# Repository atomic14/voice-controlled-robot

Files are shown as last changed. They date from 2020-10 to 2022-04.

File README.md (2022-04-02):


# Voice-Controlled Robot With the ESP32

Build your own voice-controlled robot - all you will need is an ESP32 and Microphone board (and some motors etc...).

You can watch a video of the robot in action [here (YouTube)](https://www.youtube.com/watch?v=cp2qRrhaZRA):

Demo Video (https://www.youtube.com/watch?v=cp2qRrhaZRA)

I'm using a microphone breakout board that I've built myself based around the ICS-43434 - but any microphone board will work. The code has been written so that you can either use an I2S microphone or an analogue microphone using the built-in ADC.

I would recommend using an I2S microphone if you have one as they have a lot better noise characteristics.

My board is available on [eBay](https://www.ebay.co.uk/itm/154115095985) and [Tindie](https://www.tindie.com/products/atomic14/ics-43434-i2s-mems-microphone-breakout-board/)

Other I2S microphones are equally suitable. Boards based around the INMP441 work very well.

The voice recognition is carried out using a model trained with TensorFlow and runs on the ESP32 using TensorFlow Lite. A pre-trained model is included in the Firmware folder so you can get up and running straight away.

There are two folders in this repo `model` and `firmware` check the `README.md` file in each one for complete details.

## Model

Jupyter notebooks for creating a TensorFlow Lite model for "wake word" recognition.

A pre-trained model has already been generated and added to the firmware folder.

If you want to train your own, I added a couple of extra folders to the training data they are available here:

## Firmware

ESP32 firmware built using Platform.io. This runs the neural network trying to detect the words `Left`, `Right`, `Forward` and `Backward`.

The code assumes there are two continuous servos attached to the board such as the FS90R servo - these are readily available from various suppliers and you can normally buy them with wheels as well.

# 3dPrinting

This contains the 3d models that I used to build my 2 wheeled robot. It's designed around the FS90R continuous servos and a cylindrical power bank.

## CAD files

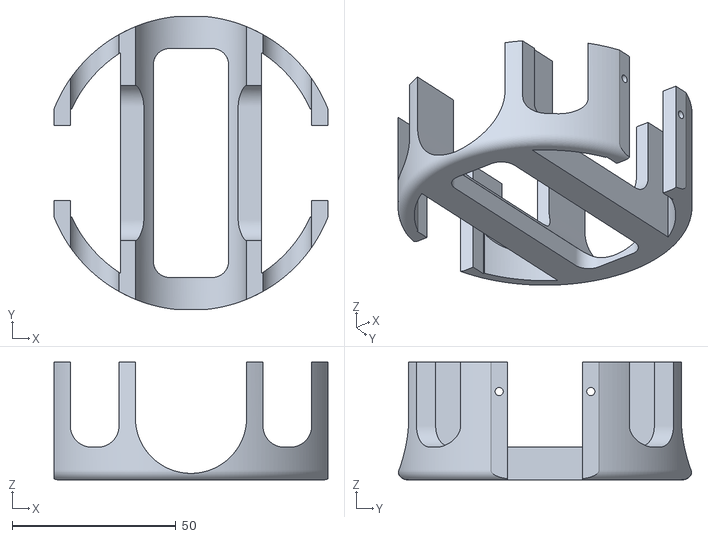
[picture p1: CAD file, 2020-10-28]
3dPrinting/2-wheeled-robot.stl
83.7 x 89.7 x 36.0

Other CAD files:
3dPrinting/2-wheeled-robot.f3z

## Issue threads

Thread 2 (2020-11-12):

Problems with CommandProcessor::processCommand and I2C

sthufnagl, 2020-11-12:
Hi,

I have a RoverC with I2C controlled Motors.
Because of this I try to change the "CommandProcessor::processCommand" and insert  some I2C Commands like below.
After the change (i.e. forward) it run once and then the Command recognition is broken. It seems related to the Wire.xxx Call.
Thanks in advance.

```
case 0: // forward
        ledcWrite(0, calcDuty(leftForward));
        ledcWrite(1, calcDuty(rightForward));
        vTaskDelay(1000 / portTICK_PERIOD_MS);
        break;
```

to
```
case 0: // forward
        Wire.beginTransmission(0X38);
        Wire...
        vTaskDelay(1000 / portTICK_PERIOD_MS);
        break;
```

sthufnagl, 2020-11-26:
Hi,

I found the solution for the M5StickC. The problem was the wrong init of I2C. How this influence the  "Command recognition" is still unknown for me.

Wrong: Wire.begin(0,26,1000);
OK:       Wire.begin(0,26,400000);

Thx

Closed 2020-11-26.

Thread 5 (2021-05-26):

Dear atomic14: there are somes question need your help, please give me some advice, thanks

maoyanru, 2021-05-26:
I have downloaded your project and it can be sucessfully compiled by platfromIo.I have been studying  for a few days,and i think i still need your guidance.
1、Can this project be completed only with esp32 and INMP441?
2、How to connect esp32 and INMP441 (the pin of INMP441 is connected to esp32)。
3、Can i use oscilloscope to view the waveform of INMP441 after powering on INMP441 alone(to make sure the INMP441 i bought is usable)
4、How to use jupyter notebook and Google Speech Commands Dataset (v0.02) to train other command model?Looking forward to you giving me the jupyter notebook project in this video for study。

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
Follow this picture to connect INMP441 and esp32 pin

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
this my hardware（esp32 and INMP441）,if i say "back"or "left" and then INMP441 detect key words,finally serial port print(testing successfully)~
                                                                                                               Think you for taking the time to reply my question
                                                                                                                your’s sincerely fans  Yao

fabiodavide97, 2021-05-27:
Dear Atomic14, i would use this project for my accademic project so i want know how change the code using 2 motor DC
Thanks for the answer

cgreening, 2021-06-07:
The best place to start would be the code in `CommandProcessor.cpp` the `processCommand` function is responsible for deciding what to do for each detected command.

At the moment it is simply changing the PWM signal to each motor. If you have a motor control board then this would be the place to make the changes.

cgreening, 2021-06-08:
@maoyanru did you solve the issues you were having?

Closed 2021-10-05.

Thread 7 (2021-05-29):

Dear Atomic14, I have some issue.

fabiodavide97, 2021-05-29:
When I run the code, appear this problem in Serial Monitor and the mic doesn't listen:

E (22702) task_wdt: Task watchdog got triggered. The following tasks did not reset the watchdog in time:
E (22702) task_wdt:  - IDLE0 (CPU 0)
E (22702) task_wdt: Tasks currently running:
E (22702) task_wdt: CPU 0: Command Detect
E (22702) task_wdt: CPU 1: loopTask

Can you help me, please ?

cgreening, 2021-06-07:
Hey Fabio,

I'll take a look. Have you made any modifications to the code?

Thanks
Chris

fabiodavide97, 2021-06-07:
I only changed the microphone connection pin:
sck ---> GPIO25
WS ----> GPIO33
SD ----> GPIO32
VDD --->3.3V
GND ---> GND

cgreening, 2021-06-07:
Hmm, that shouldn't make any difference. Let me run it up locally and see if something has changed with the underlying Arduino frameworks.

fabiodavide97, 2021-06-07:
could it be a microphone problem? I use an INMP441.

cgreening, 2021-06-07:
It should matter - though I guess if there's weird data coming from the microphone it could trigger some odd behaviour.

In the code, we see the watch dog timeout to 10 seconds so it really shouldn't be triggering at all.

```
  // make sure we don't get killed for our long running tasks
  esp_task_wdt_init(10, false);
```

This is what you should see on the output (I'm running this with no microphone connected at all).

```
Average detection time 103ms
Average detection time 103ms
Average detection time 103ms
Average detection time 103ms
Average detection time 103ms
Average detection time 103ms
Average detection time 103ms
Average detection time 103ms
```

cgreening, 2021-06-07:
I've added a vTaskDelay to the loop function - I'm not sure if will help as I can't create the issue - I'll do some more investigation this evening.

fabiodavide97, 2021-06-07:
Starting up
Loading model
12 bytes lost due to alignment. To avoid this loss, please make sure the tensor_arena is 16 bytes aligned.
Used bytes 22644

Output Size 1

Created Neral Net
m_pooled_energy_size=43
Created audio processor
Starting i2s
E (22715) task_wdt: Task watchdog got triggered. The following tasks did not reset the watchdog in time:
E (22715) task_wdt:  - IDLE0 (CPU 0)
E (22715) task_wdt: Tasks currently running:
E (22715) task_wdt: CPU 0: Command Detect
E (22715) task_wdt: CPU 1: IDLE1
Average detection time 155ms
E (32715) task_wdt: Task watchdog got triggered. The following tasks did not reset the watchdog in time:
E (32715) task_wdt:  - IDLE0 (CPU 0)
E (32715) task_wdt: Tasks currently running:
E (32715) task_wdt: CPU 0: Command Detect
E (32715) task_wdt: CPU 1: IDLE1
E (42715) task_wdt: Task watchdog got triggered. The following tasks did not reset the watchdog in time:
E (42715) task_wdt:  - IDLE0 (CPU 0)
E (42715) task_wdt: Tasks currently running:
E (42715) task_wdt: CPU 0: Command Detect
E (42715) task_wdt: CPU 1: IDLE1
Average detection time 155ms
E (52715) task_wdt: Task watchdog got triggered. The following tasks did not reset the watchdog in time:
E (52715) task_wdt:  - IDLE0 (CPU 0)
E (52715) task_wdt: Tasks currently running:
E (52715) task_wdt: CPU 0: Command Detect
E (52715) task_wdt: CPU 1: IDLE1

This is the Serial Monitor.

cgreening, 2021-06-07:
I think since the device is not restarting you can probably ignore the message. Though I'm not sure why you are seeing it with the watchdog pretty much disabled.

Onto your microphone issue - can you check that in the `config.h` file the line

```
#define USE_I2S_MIC_INPUT
```

Is not commented out. I noticed in the previous code that it was commented out which would switch the device into using the ADC instead of the I2S microphone.

cgreening, 2021-06-07:
Also, your detection time seems to be very slow. What device are you using?

fabiodavide97, 2021-06-07:
I'm using esp32

cgreening, 2021-06-07:
Which dev board are you using?

fabiodavide97, 2021-06-07:
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

cgreening, 2021-06-07:
Looks pretty standard. So there are a couple of places that you can debug your microphone.

In `CommandDetector.cpp` you can try logging out the value of `best_score` and `best_index` just after line 96.

In `AudioProcessor.cpp` you could log out the max value you are getting from the microphone - you can log out the value of max on line 114 and see if it changes when you speak into the microphone.

To really test it, you could try one of my other projects - the simplest one is probably `https://github.com/atomic14/ICS-43434-breakout-board` it hs a server that the samples are sent to so you can load into something like Audacity - or even just look at the data using hexdump to see if it has non zero values.

You can also just Serial print the values coming from the microphone.

cgreening, 2021-06-07:
I've tested the code locally here and all seems well, so I think your first step would be to confirm the microphone is working as expected.

cgreening, 2021-06-07:
I've created a really simple test sketch that you can use to test your microphone - let me know how you get on: https://github.com/atomic14/esp32-i2s-mic-test

fabiodavide97, 2021-06-07:
dear Atomic 14 the problem is the microphone because the code generates this waveform.
it does not detect sound waves. I don't know how to fix it and hope you can help me.
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

cgreening, 2021-06-07:
Double-check the wiring of your microphone - is it definitely wired up correctly?

Make sure the L/R pin is connected to GND.

If you draw out your connections I can double-check them for you.

cgreening, 2021-06-07:
Actually, I get exactly what you are seeing when the SD line is disconnected.

fabiodavide97, 2021-06-07:
Yes, the pin is correctly wireds up

fabiodavide97, 2021-06-07:
Dear Atomic 14 finally the code works. The problem was the microphone. Some pins were not soldered well and therefore made no contact.
Thank you so much for helping me.

fabiodavide97, 2021-06-07:
Dear Atomic 14, I would like to ask you something else. I have 2 DC motors connected to the L298N module. How can I modify the code to make them work?

cgreening, 2021-06-08:
Take a look here: https://github.com/atomic14/voice-controlled-robot/issues/5#issuecomment-855772115

Closed 2021-06-08.

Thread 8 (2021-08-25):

FreeRTOS dependency is missing

omakood, 2021-08-25:
Sorry, I'm beginner in PlatformIO and I can't compile the project:

Processing esp32doit-devkit-v1 (platform: espressif32; board: esp32doit-devkit-v1; framework: arduino)
------
Verbose mode can be enabled via `-v, --verbose` option
CONFIGURATION: https://docs.platformio.org/page/boards/espressif32/esp32doit-devkit-v1.html
PLATFORM: Espressif 32 (3.3.1) > DOIT ESP32 DEVKIT V1
HARDWARE: ESP32 240MHz, 320KB RAM, 4MB Flash
DEBUG: Current (esp-prog) External (esp-prog, iot-bus-jtag, jlink, minimodule, olimex-arm-usb-ocd, olimex-arm-usb-ocd-h, olimex-arm-usb-tiny-h, olimex-jtag-tiny, tumpa)
PACKAGES:
 - framework-arduinoespressif32 3.10006.210326 (1.0.6)
 - tool-esptoolpy 1.30100.210531 (3.1.0)
 - toolchain-xtensa32 2.50200.97 (5.2.0)
LDF: Library Dependency Finder -> http://bit.ly/configure-pio-ldf
LDF Modes: Finder ~ chain, Compatibility ~ soft
Found 32 compatible libraries
Scanning dependencies...
Dependency Graph
|-- <audio_processor>
|   |-- <audio_input>
|-- <audio_input>
|-- <neural_network>
|   |-- <tfmicro>
|-- <WiFi> 1.0
Building in release mode
Compiling .pio/build/esp32doit-devkit-v1/src/CommandDetector.cpp.o
Compiling .pio/build/esp32doit-devkit-v1/src/main.cpp.o
In file included from src/CommandDetector.cpp:2:0:
lib/audio_input/I2SSampler.h:3:31: fatal error: FreeRTOS/FreeRTOS.h: No such file or directory
compilation terminated.
Compiling .pio/build/esp32doit-devkit-v1/libbcc/audio_input/ADCSampler.cpp.o
In file included from lib/audio_input/ADCSampler.h:4:0,
Compiling .pio/build/esp32doit-devkit-v1/libbcc/audio_input/I2SMicSampler.cpp.o
                 from lib/audio_input/ADCSampler.cpp:1:
lib/audio_input/I2SSampler.h:3:31: fatal error: FreeRTOS/FreeRTOS.h: No such file or directory
compilation terminated.
*** [.pio/build/esp32doit-devkit-v1/src/CommandDetector.cpp.o] Error 1
*** [.pio/build/esp32doit-devkit-v1/libbcc/audio_input/ADCSampler.cpp.o] Error 1
In file included from lib/audio_input/I2SMicSampler.h:4:0,
                 from lib/audio_input/I2SMicSampler.cpp:1:
lib/audio_input/I2SSampler.h:3:31: fatal error: FreeRTOS/FreeRTOS.h: No such file or directory
compilation terminated.
*** [.pio/build/esp32doit-devkit-v1/libbcc/audio_input/I2SMicSampler.cpp.o] Error 1
In file included from lib/audio_input/I2SMicSampler.h:4:0,
                 from src/main.cpp:5:
lib/audio_input/I2SSampler.h:3:31: fatal error: FreeRTOS/FreeRTOS.h: No such file or directory
compilation terminated.
*** [.pio/build/esp32doit-devkit-v1/src/main.cpp.o] Error 1

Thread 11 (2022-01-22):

print(len(train), len(test), len(validate)) always returns 0 0 0

chrisakira, 2022-01-22:
I'm using tensorflow 2.7.0 installed on a VM with ubuntu 20.04.03

The output on the first process word part is

Processing words: 100%
5/5 [00:00<00:00, 9.56it/s]

2022-01-22 16:02:50.608038: W tensorflow/stream_executor/platform/default/dso_loader.cc:64] Could not load dynamic library 'libcuda.so.1'; dlerror: libcuda.so.1: cannot open shared object file: No such file or directory
2022-01-22 16:02:50.608082: W tensorflow/stream_executor/cuda/cuda_driver.cc:269] failed call to cuInit: UNKNOWN ERROR (303)
2022-01-22 16:02:50.608126: I tensorflow/stream_executor/cuda/cuda_diagnostics.cc:156] kernel driver does not appear to be running on this host (Onegai): /proc/driver/nvidia/version does not exist
2022-01-22 16:02:50.608395: I tensorflow/core/platform/cpu_feature_guard.cc:151] This TensorFlow binary is optimized with oneAPI Deep Neural Network Library (oneDNN) to use the following CPU instructions in performance-critical operations:  AVX2
To enable them in other operations, rebuild TensorFlow with the appropriate compiler flags.

Processing words: 100%
31/31 [00:03<00:00, 8.80it/s]

0 0 0

And the process background noise is

Processing Background Noise: 0it [00:00, ?it/s]

0 0 0

I don't have idea what could be wrong...
Help a poor student triyng to learn tensorflow please

chrisakira, 2022-01-23:
Ok i'ts a bad idea to use your jupyter notebook installed via Anaconda....
It will not find the training archives ( or at least mine did'nt)...
Lesson of the day..... Just follow the readme and it works....

Closed 2022-01-23.

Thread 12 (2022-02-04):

Voice recognition development

Anugaradhawa, 2022-02-04:
Can we develop this project to recognize the all commands we know?

cgreening, 2022-03-04:
There's a limit to what you can do with a model small enough to run quickly on an esp32.

You can use a larger more complex model with more preprocessing and recognise more words, but you might struggle to get it to run on the esp32.

Anugaradhawa, 2022-03-05:
what type of development board I can run when I make a model like that? I have a question, the Alexa project and this voice control car's code is really written by yourself? or did you get this code from another person?

cgreening, 2022-03-05:
You would probably find a raspberry pi more suitable.

Very strange question. Yes, I wrote the code.

Anugaradhawa, 2022-03-05:
wow really awesome. you are a genius. These days  I am doing a C course after I will do a C++ course then I will try your projects. before I had not any knowledge now I have a  little bit of knowledge about C. I also want to write codes like you.

Closed 2022-03-05.

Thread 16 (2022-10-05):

training_spectrogram.npz is not found

gjohnson0720, 2022-10-05:
I am attempting to regenerate the Train Model.  When running Train Model-All Words.ipynb in jupyter, I am getting this error:
---------------------------------------------------------------------------
FileNotFoundError                         Traceback (most recent call last)
Cell In [7], line 2
      1 # Load up the sprectrograms and labels
----> 2 training_spectrogram = np.load('training_spectrogram.npz')
Is this file supposed to be included in the repo?
Thanks.

Closed 2022-10-06.

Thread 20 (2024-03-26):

Using the Model with Raspberry Pi 4B and a USB Mic Input

payalmohnani, 2024-03-26:
I have been trying to use this model with Raspberry Pi 4B while the input is from the USB Mic.

While writing inference for the model for Raspberry Pi, I am unable to take the input audio(preferably in the sliding widow format) and detect the command. I am only concerned with detecting the input here.

I did try multiple code snippets but ran into some issue. And the firmware code is a bit less commented for someone like me (beginner ) to get.

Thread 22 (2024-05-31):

what's pin of motors?

salvatore1907, 2024-05-31:
i know mic pins are:

#define I2S_MIC_SERIAL_CLOCK GPIO_NUM_33
#define I2S_MIC_LEFT_RIGHT_CLOCK GPIO_NUM_26
#define I2S_MIC_SERIAL_DATA GPIO_NUM_25

whats pin of two servos?

Closed 2024-06-05.

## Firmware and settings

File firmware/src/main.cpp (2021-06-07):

#include <Arduino.h>
#include <WiFi.h>
#include <driver/i2s.h>
#include <esp_task_wdt.h>
#include "I2SMicSampler.h"
#include "ADCSampler.h"
#include "config.h"
#include "CommandDetector.h"
#include "CommandProcessor.h"

// i2s config for using the internal ADC
i2s_config_t adcI2SConfig = {
    .mode = (i2s_mode_t)(I2S_MODE_MASTER | I2S_MODE_RX | I2S_MODE_ADC_BUILT_IN),
    .sample_rate = 16000,
    .bits_per_sample = I2S_BITS_PER_SAMPLE_16BIT,
    .channel_format = I2S_CHANNEL_FMT_ONLY_LEFT,
    .communication_format = I2S_COMM_FORMAT_I2S_LSB,
    .intr_alloc_flags = ESP_INTR_FLAG_LEVEL1,
    .dma_buf_count = 4,
    .dma_buf_len = 64,
    .use_apll = false,
    .tx_desc_auto_clear = false,
    .fixed_mclk = 0};

// i2s config for reading from both channels of I2S
i2s_config_t i2sMemsConfigBothChannels = {
    .mode = (i2s_mode_t)(I2S_MODE_MASTER | I2S_MODE_RX),
    .sample_rate = 16000,
    .bits_per_sample = I2S_BITS_PER_SAMPLE_32BIT,
    .channel_format = I2S_MIC_CHANNEL,
    .communication_format = i2s_comm_format_t(I2S_COMM_FORMAT_I2S),
    .intr_alloc_flags = ESP_INTR_FLAG_LEVEL1,
    .dma_buf_count = 4,
    .dma_buf_len = 64,
    .use_apll = false,
    .tx_desc_auto_clear = false,
    .fixed_mclk = 0};

// i2s microphone pins
i2s_pin_config_t i2s_mic_pins = {
    .bck_io_num = I2S_MIC_SERIAL_CLOCK,
    .ws_io_num = I2S_MIC_LEFT_RIGHT_CLOCK,
    .data_out_num = I2S_PIN_NO_CHANGE,
    .data_in_num = I2S_MIC_SERIAL_DATA};

// This task does all the heavy lifting for our application
void applicationTask(void *param)
{
  CommandDetector *commandDetector = static_cast<CommandDetector *>(param);

  const TickType_t xMaxBlockTime = pdMS_TO_TICKS(100);
  while (true)
  {
    // wait for some audio samples to arrive
    uint32_t ulNotificationValue = ulTaskNotifyTake(pdTRUE, xMaxBlockTime);
    if (ulNotificationValue > 0)
    {
      commandDetector->run();
    }
  }
}

void setup()
{
  Serial.begin(115200);
  delay(1000);
  Serial.println("Starting up");

  // make sure we don't get killed for our long running tasks
  esp_task_wdt_init(10, false);

  // start up the I2S input (from either an I2S microphone or Analogue microphone via the ADC)
#ifdef USE_I2S_MIC_INPUT
  // Direct i2s input from INMP441 or the SPH0645
  I2SSampler *i2s_sampler = new I2SMicSampler(i2s_mic_pins, false);
#else
  // Use the internal ADC
  I2SSampler *i2s_sampler = new ADCSampler(ADC_UNIT_1, ADC_MIC_CHANNEL);
#endif
  // the command processor
  CommandProcessor *command_processor = new CommandProcessor();

  // create our application
  CommandDetector *commandDetector = new CommandDetector(i2s_sampler, command_processor);

  // set up the i2s sample writer task
  TaskHandle_t applicationTaskHandle;
  xTaskCreatePinnedToCore(applicationTask, "Command Detect", 8192, commandDetector, 1, &applicationTaskHandle, 0);

  // start sampling from i2s device - use I2S_NUM_0 as that's the one that supports the internal ADC
#ifdef USE_I2S_MIC_INPUT
  i2s_sampler->start(I2S_NUM_0, i2sMemsConfigBothChannels, applicationTaskHandle);
#else
  i2s_sampler->start(I2S_NUM_0, adcI2SConfig, applicationTaskHandle);
#endif
}

void loop()
{
  vTaskDelay(pdMS_TO_TICKS(1000));
}

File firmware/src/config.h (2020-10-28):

// are you using an I2S microphone - comment this out if you want to use an analog mic and ADC input
#define USE_I2S_MIC_INPUT

// I2S Microphone Settings
// Which channel is the I2S microphone on? I2S_CHANNEL_FMT_ONLY_LEFT or I2S_CHANNEL_FMT_ONLY_RIGHT
#define I2S_MIC_CHANNEL I2S_CHANNEL_FMT_ONLY_LEFT
// #define I2S_MIC_CHANNEL I2S_CHANNEL_FMT_ONLY_RIGHT
#define I2S_MIC_SERIAL_CLOCK GPIO_NUM_33
#define I2S_MIC_LEFT_RIGHT_CLOCK GPIO_NUM_26
#define I2S_MIC_SERIAL_DATA GPIO_NUM_25

// Analog Microphone Settings - ADC1_CHANNEL_7 is GPIO35
#define ADC_MIC_CHANNEL ADC1_CHANNEL_7

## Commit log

2020-10-28 Adds 3d models
    [2-wheeled-robot.f3z, 2-wheeled-robot.stl]
2020-12-08 Fixes build error for adc mic
    [config.h, main.cpp]
2020-12-08 Fixes i2s adc compile error
    [main.cpp]
2021-05-23 Fixes compilation of fmax and fmin which conflicts with Arduino
2021-06-07 Adds a delay to the loop to see if it fixes other people's WDT issues
    [main.cpp]
